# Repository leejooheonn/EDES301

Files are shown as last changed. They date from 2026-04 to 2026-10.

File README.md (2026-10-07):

# Hydra-Gotchi | Embedded Smart Scale






**Hydra-Gotchi** is an ARM-based Linux embedded smart scale built on the BeagleBone Black. The system integrates analog force sensing, custom signal calibration software, and interactive user feedback via an I2C OLED display, GPIO digital inputs, and a piezo audio signal.

---

## 📖 Full Build Log & Hardware Schematics

For detailed hardware schematics, wiring diagrams, laser-cut enclosure vectors, and physical build photographs, check out the full project writeup on **Hackster.io**:

👉 **[View the Hydra-Gotchi Project on Hackster.io](https://www.hackster.io/jl587/hydrationhelper-0f8108) 

---

## 🛠️ Hardware & System Architecture

The hardware architecture combines a custom circuit assembly with a laser-cut, stress-tested enclosure designed to standardize physical load distribution across the Force Sensitive Resistor (FSR) to eliminate mechanical measurement noise.

### Hardware Components
* **SBC (Single-Board Computer):** BeagleBone Black (AM335x ARM Cortex-A8)
* **Weight Sensing:** Force Sensitive Resistor (FSR) connected via Analog-to-Digital Converter (ADC)
* **Visual Display:** SSD1306 OLED Display interfaced via **I2C**
* **Inputs & Audio:** Digital push button (**GPIO**) and Piezoelectric Buzzer (**GPIO**)
* **Physical Assembly:** Custom soldered PCB assembly housed in a laser-cut acrylic enclosure

### Block Diagram

```text
  +--------------------------------------------------------------+
  |                      BeagleBone Black                        |
  |                                                              |
  |   +-------------+      +-------------+      +------------+   |
  |   |   ADC Pin   |      |  I2C Bus    |      | GPIO Pins  |   |
  |   +------+------+      +------+------+      +-----+------+   |
  +----------|--------------------|-------------------|----------+
             |                    |                   |
             v                    v                   v
     [ FSR Sensor ]        [ OLED Display ]     [ Push Button / ]
    (Analog Weight)         (128x64 I2C)        [ Piezo Buzzer  ]

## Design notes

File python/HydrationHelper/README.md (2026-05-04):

<h1>HydrationHelper</h1>

## About the Project 
HydrationHelper is a tool to help people reach their daily water goals. It works to motivate users to drink water by having a virtual pet track the weight of the water bottle and setting a time period for the water bottle to be finished by. The sensor then checks the water bottle at the end of the time period and depending on if the water is full or empty, the virtual pet acts accordingly. 

## Features
* Goal setting: the users can set their time goal for finishing their water bottle
* Calibration: tracks the weight of the full water bottle and the empty water bottle to calibrate the program
* Project presentation: the project proposal can be found in the `docs/` folder

## Repository Structure
* `docs/` - Contains the project presentation and other documentation.
* `HydrationHelper/` - *Contains source code, and images used for the virtual pet*

## Installation and Set-up 
To run this project locally, ensure you have Python3 installed. 
1) Clone the repository
2) Install the required dependencies
   `pip install Adafruit-BBIO`
   `pip install Pillow`
   `pip install Adafruit-Blinka`
   `pip install adafruit-circuitpython-ssd1306`
3) Run the application by entering the HydrationHelper directory and run `python3 calibration.py` to calibrate and then `python3 main.py` to start the HydrationHelper

> **Troubleshooting:** If you receive a "Permission Denied" error regarding hardware access (ADC or I2C), your user may not have the correct permissions. In that case, you can run the program with administrator privileges: `sudo python3 main.py` (Note: If you need to run it with sudo, you may need to install the requirements globally using `sudo pip3 install -r {dependency}`).

## Built With
* Python, BeagleBoard

# Author
* Jooheon Lee EDES301

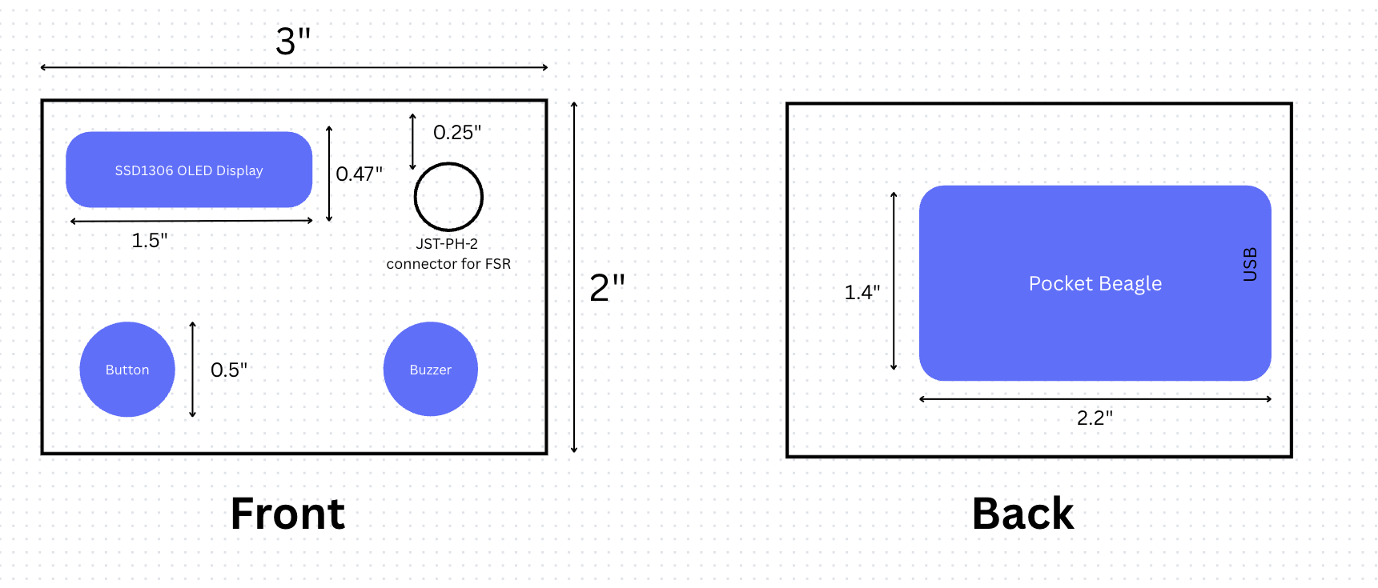
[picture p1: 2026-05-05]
project_02/docs/updated_mechanical_diagram.png

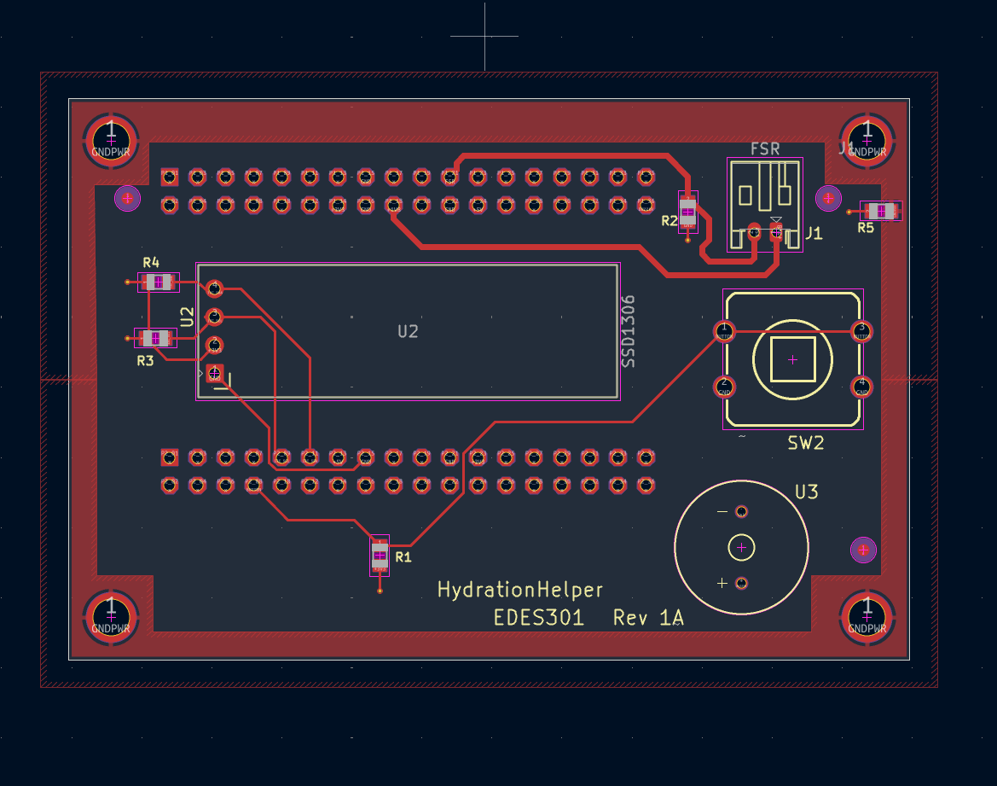
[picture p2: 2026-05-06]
project_02/docs/front_layers.png

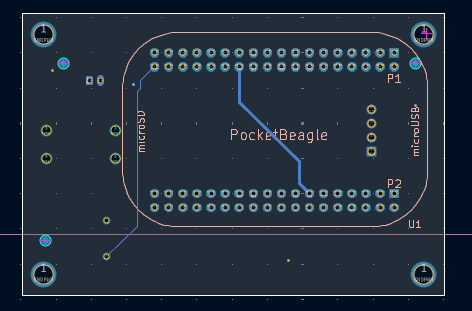
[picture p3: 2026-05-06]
project_02/docs/back_layers.png

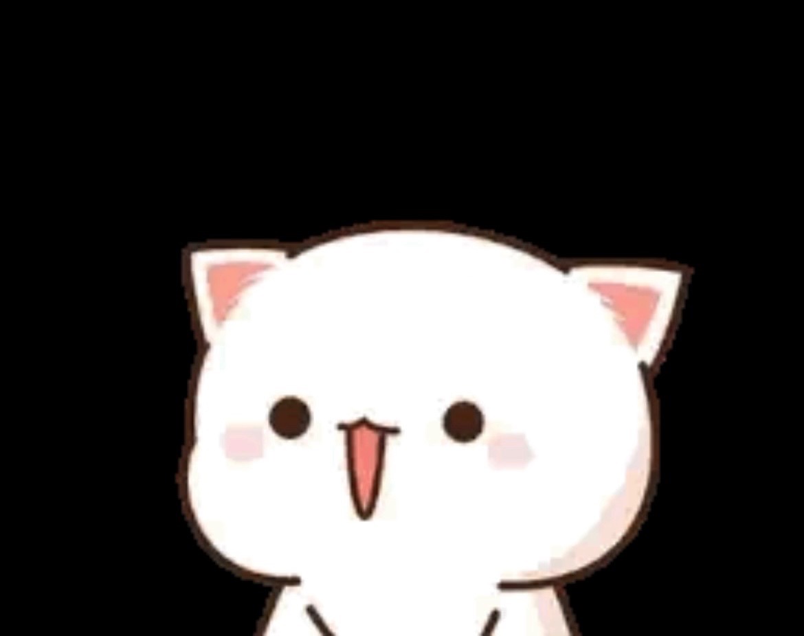
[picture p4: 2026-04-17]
python/HydrationHelper/jumping_cat_3.jpeg

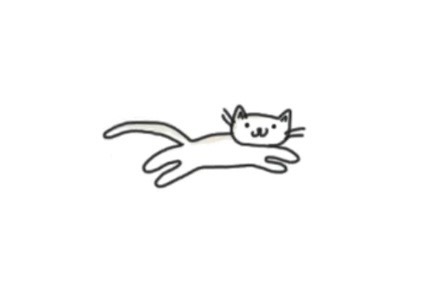
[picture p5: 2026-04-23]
python/HydrationHelper/running_cat_1.jpeg

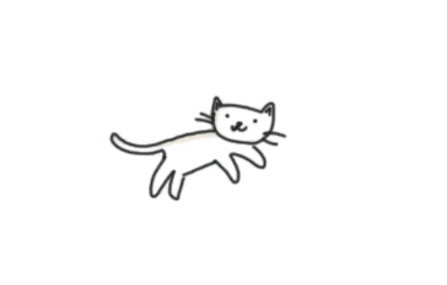
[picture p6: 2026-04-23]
python/HydrationHelper/running_cat_6.jpeg

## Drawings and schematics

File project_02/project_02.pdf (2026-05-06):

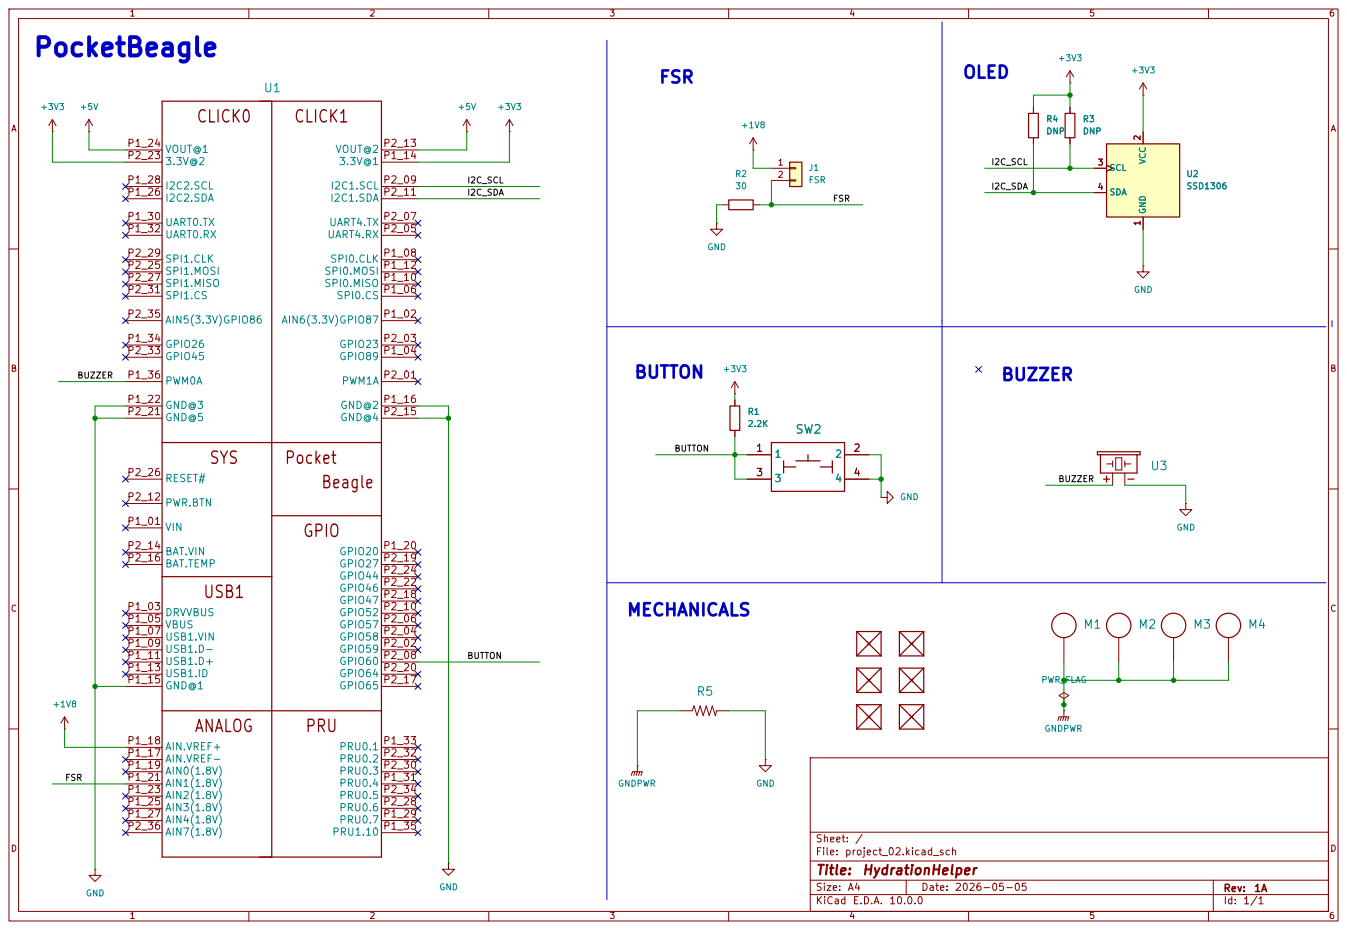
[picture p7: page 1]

Size: A4 | Rev: 1A

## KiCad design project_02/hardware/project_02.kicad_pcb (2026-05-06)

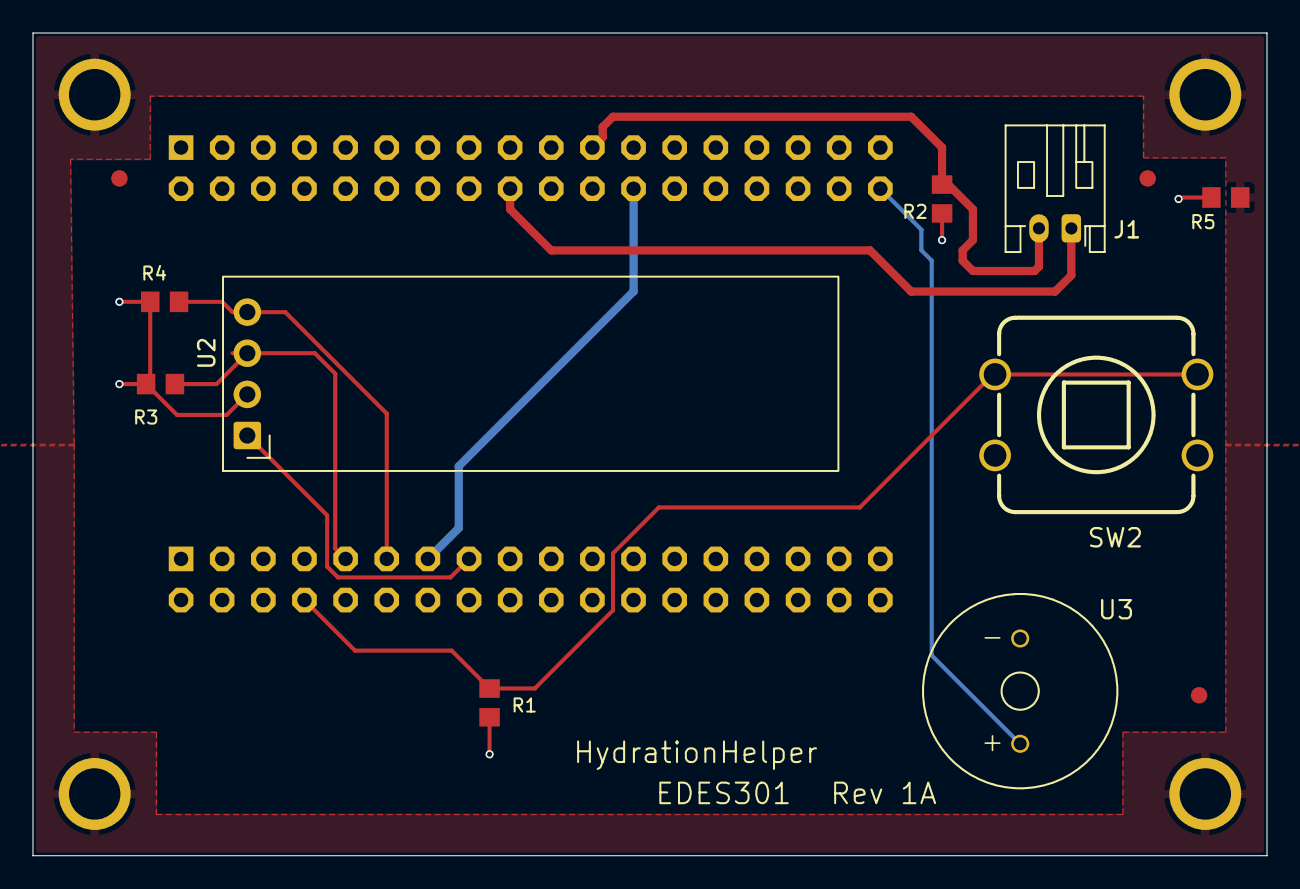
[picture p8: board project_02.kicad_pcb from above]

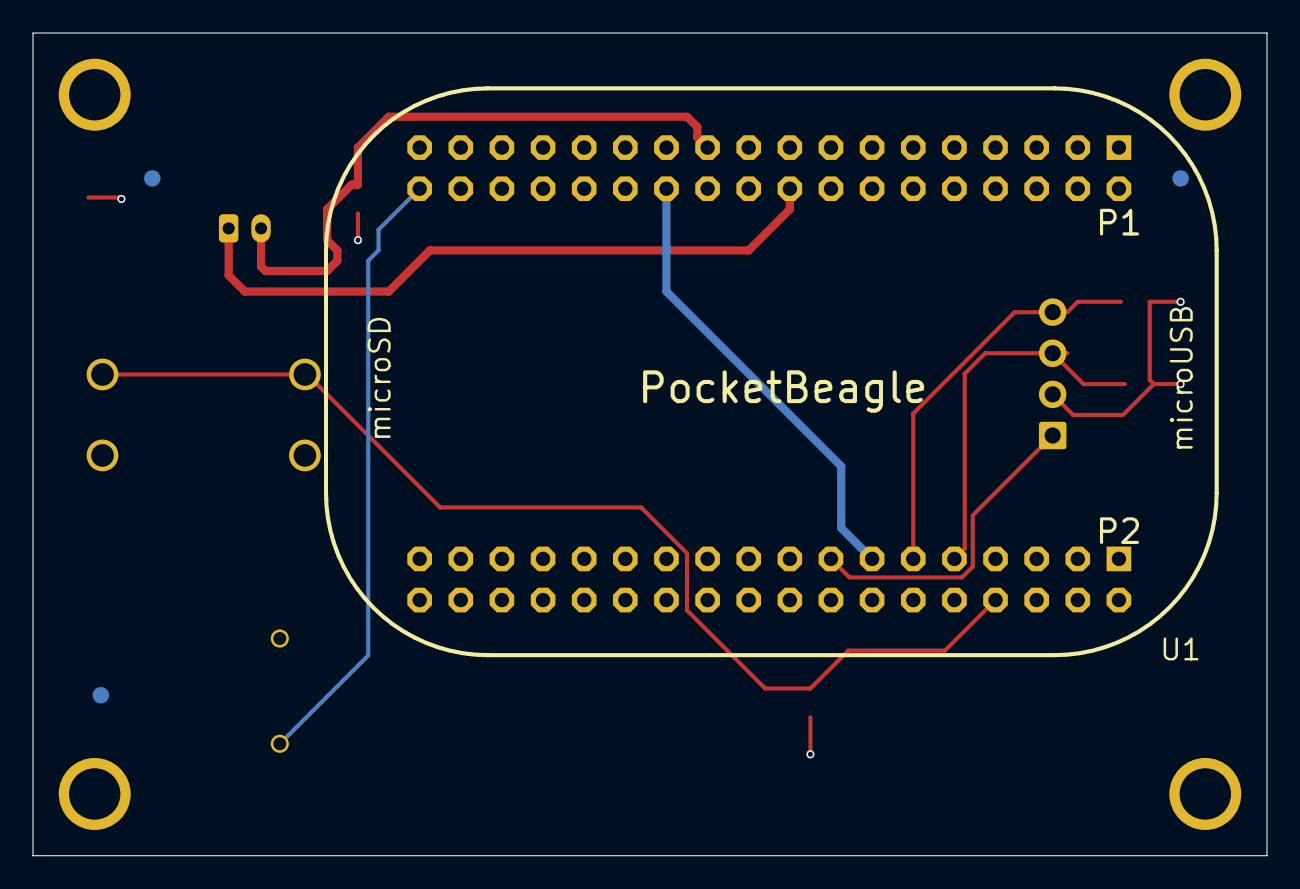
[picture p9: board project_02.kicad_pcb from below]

Board: 4 copper layers, 76.2 x 50.8 mm, 20 parts (4 on the bottom side), 10 nets.

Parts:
FUD1, FUD2, FUD3, FUD4, FUD5, FUD6: FIDUCIAL_40MIL
J1: FSR; JST_PH_S2B-PH-K_1x02_P2.00mm_Horizontal
M1, M2, M3, M4: MOUNTING_HOLE
R1: 2.2K; 2.2KR
R2: 30; 30R
R3, R4: DNP; 2.2KR
R5: R0805
SW2: BUTTON_12.5MM
U1: POCKETBEAGLE
U2: SSD1306; ER_OLEDM0.91_1x-I2C
U3: BUZZER_6.5MM

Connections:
+1V8: J1.1, U1.P1_18 (AIN.VREF+)
+3V3: R1.2, R3.1, R4.1, U1.P1_14 (3.3V@1), U1.P2_23 (3.3V@2), U2.2 (VCC)
+5V: U1.P1_24 (VOUT@1), U1.P2_13 (VOUT@2)
/BUTTON: R1.1, SW2.1, SW2.3, U1.P2_08 (GPIO60)
/BUZZER: U1.P1_36 (PWM0A), U3.+
/FSR: J1.2, R2.2, U1.P1_21 (AIN1(1.8V))
/I2C_SCL: R3.2, U1.P2_09 (I2C1.SCL), U2.3 (SCL)
/I2C_SDA: R4.2, U1.P2_11 (I2C1.SDA), U2.4 (SDA)
GND: R2.1, R5.2, SW2.2, SW2.4, U1.P1_15 (GND@1), U1.P1_16 (GND@2), U1.P1_22 (GND@3), U1.P2_15 (GND@4), U1.P2_21 (GND@5), U2.1 (GND), U3.-
GNDPWR: M1.1 (1_1), M2.1 (1_1), M3.1 (1_1), M4.1 (1_1), R5.1

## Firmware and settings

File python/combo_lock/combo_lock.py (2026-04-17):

"""
--------------------------------------------------------------------------
Combination Lock
--------------------------------------------------------------------------
License:   
Copyright 2026 <NAME>

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
1. Redistributions of source code must retain the above copyright notice, this 
list of conditions and the following disclaimer.

2. Redistributions in binary form must reproduce the above copyright notice, 
this list of conditions and the following disclaimer in the documentation 
and/or other materials provided with the distribution.

3. Neither the name of the copyright holder nor the names of its contributors 
may be used to endorse or promote products derived from this software without 
specific prior written permission.

THIS SOFTWARE IS PROVIDED BY THE COPYRIGHT HOLDERS AND CONTRIBUTORS "AS IS" 
AND ANY EXPRESS OR IMPLIED WARRANTIES, INCLUDING, BUT NOT LIMITED TO, THE 
IMPLIED WARRANTIES OF MERCHANTABILITY AND FITNESS FOR A PARTICULAR PURPOSE ARE 
DISCLAIMED. IN NO EVENT SHALL THE COPYRIGHT HOLDER OR CONTRIBUTORS BE LIABLE 
FOR ANY DIRECT, INDIRECT, INCIDENTAL, SPECIAL, EXEMPLARY, OR CONSEQUENTIAL 
DAMAGES (INCLUDING, BUT NOT LIMITED TO, PROCUREMENT OF SUBSTITUTE GOODS OR 
SERVICES; LOSS OF USE, DATA, OR PROFITS; OR BUSINESS INTERRUPTION) HOWEVER 
CAUSED AND ON ANY THEORY OF LIABILITY, WHETHER IN CONTRACT, STRICT LIABILITY, 
OR TORT (INCLUDING NEGLIGENCE OR OTHERWISE) ARISING IN ANY WAY OUT OF THE USE 
OF THIS SOFTWARE, EVEN IF ADVISED OF THE POSSIBILITY OF SUCH DAMAGE.
--------------------------------------------------------------------------

Use the following hardware components to make a programmable combination lock:  
  - HT16K33 Display
  - Button
  - Red LED
  - Green LED
  - Potentiometer (analog input)
  - Servo

Requirements:
  - Hardware:
    - When locked:   Red LED is on; Green LED is off; Servo is "closed"; Display is unchanged
    - When unlocked: Red LED is off; Green LED is on; Servo is "open"; Display is "----"
    - Display shows value of potentiometer (raw value of analog input divided by 8)
    - Button
      - Waiting for a button press should allow the display to update (if necessary) and return any values
      - Time the button was pressed should be recorded and returned
    - User interaction:
      - Needs to be able to program the combination for the “lock”
        - Need to be able to input three values for the combination to program or unlock the “lock”
      - Combination lock should lock when done programming and wait for combination input
      - If combination is unsuccessful, the lock should go back to waiting for combination input
      - If combination was successful, the lock should unlock
        - When unlocked, pressing button for less than 2s will re-lock the lock; greater than 2s will allow lock to be re-programmed

Uses:
  - HT16K33 display library developed in class
    - Library updated to add "set_digit_raw()", "set_colon()"

"""
import time
import sys
import os
 
sys.path.append('/var/lib/cloud9/EDES301/python')

import ht16k33           as HT16K33
import button             as BUTTON
import potentiometer as POT
import servo               as SERVO
import led                   as LED
from buzzer import buzzer_music         as MUSIC

# ------------------------------------------------------------------------
# Constants
# ------------------------------------------------------------------------

SERVO_LOCK         = 100     # Fully anti-clockwise
SERVO_UNLOCK       = 0       # Fully clockwise

POT_DIVIDER        = 8       # Divider used to help reduce potentiometer granularity

# ------------------------------------------------------------------------
# Global variables
# ------------------------------------------------------------------------

# None

# ------------------------------------------------------------------------
# Functions / Classes
# ------------------------------------------------------------------------

class CombinationLock():
    """ CombinationLock """
    reset_time     = None
    button         = None
    red_led        = None
    green_led      = None
    potentiometer  = None
    servo          = None
    display        = None
    buzzer         = None
    debug          = None
    
    def __init__(self, reset_time=2.0, button="P2_35", 
                       red_led="P2_6", green_led="P2_4",
                       potentiometer="P1_19", servo="P1_36", 
                       i2c_bus=1, i2c_address=0x70,
                       buzzer="P2_1", debug=False):
        """ Initialize variables and set up display """

        self.reset_time     = reset_time
        self.button         = BUTTON.Button(button)
        self.red_led        = LED.LED(red_led)
        self.green_led      = LED.LED(green_led)
        self.potentiometer  = POT.Potentiometer(potentiometer)
        self.servo          = SERVO.Servo(servo, default_position=SERVO_UNLOCK)
        self.display        = HT16K33.HT16K33(i2c_bus, i2c_address)
        self.debug          = debug
        self.buzzer         = MUSIC.BuzzerMusic(buzzer)
        self._setup()
    
    # End def
    
    
    def _setup(self):
        """Setup the hardware components."""

        # Button / LEDs / Potentiometer / Servo 
        #   - All initialized by libraries when instanitated
        
        # set default state 
        self.unlock()

    # End def


    def lock(self):
        """Lock the lock:
               - Turn on red LED; Turn off green LED
               - Set servo to closed
        """
        if self.debug:
            print("lock()")
        
        # Set LEDs
        self.green_led.off()
        self.red_led.on()
        # Set servo to "locked"
        self.servo.turn(SERVO_LOCK)

    # End def


    def unlock(self):
        """Unlock the lock.
               - Turn off red LED; Turn on green LED
               - Set servo to open
               - Set display to "----"
        """
        if self.debug:
            print("unlock()")
            
        # Set LEDs
        self.green_led.on()
        self.red_led.off()
        
        # Set servo to "unlocked"
        self.servo.turn(SERVO_UNLOCK)

        # Set display to dash
        self.set_display_dash()
        
        self.buzzer.play_song_from_list(1)

    # End def


    def show_analog_value(self):
        """Show the analog value on the screen:
               - Read raw analog value
               - Divide by 4 (remove two LSBs)
               - Display value
               - Return value
        """
        if self.debug:
            print("show_analog_value()")
            
        # Read value from Potentiometer
        value = self.potentiometer.get_value()
        
        # Divide value by POT_DIVIDER
        value = int(value // POT_DIVIDER)
        
        # Update display (must be an integer)
        self.display.update(value)
        
        # Return value
        return value

    # End def


    def input_combination(self):
        """Input a combination for the lock:
               - Wait for a button press doing nothing (start of user inputing combination)
               - Repeat 3 time:
                 - Wait for button press; show analog value
                 - Record analog value
               - Return combination
        """
        # Initialize combination array
        combination = [None, None, None]
        
        for i in range(3):
            # Update display with current input
            self.set_display_input(i+1)

            # Wait for button press (do nothing)
            self.button.wait_for_press()
            
            # Set button unpressed callback function
            self.button.set_unpressed_callback(self.show_analog_value)

            # Wait for button press (show analog value)
            self.button.wait_for_press()

            # Get callback function value from button
            value = self.button.get_unpressed_callback_value()
            
            # Remove button unpressed callback 
            self.button.set_unpressed_callback(None)

            # Record Analog value
            combination[i] = value

        if self.debug:
            print(combination)
            
        return combination

    # End def


    def run(self):
        """Execute the main program."""
        combination                  = [None, None, None]  # Combination
        combo_attempt                = [None, None, None]  # Combination attempt
        program                      = True
        
        # Lock was unlocked in _setup()
        time.sleep(1)
                
        while(1):
            
            # Program the lock
            if (program):
                if self.debug:
                    print("Program Lock")
                
                # Set display
                self.set_display_prog()
                
                # Wait for button press (do nothing)
                self.button.wait_for_press()
                
                # Get combination
                combination = self.input_combination()
                
                # Lock the lock
                self.lock()
                
                # Set program lock to False
                program = False

            # Set Display to try combination
            self.set_display_try()

            # Wait for button press (do nothing)
            self.button.wait_for_press()
            
            # Get combination
            combo_attempt = self.input_combination()

            # Compare attempt against combination
            combo_pass = True

            for i in range(2):
                if combination[i] != combo_attempt[i]:
                    combo_pass = False

            # If combination passed
            if combo_pass:
                if self.debug:
                    
                    print("Combination Passed")
                # Unlock the lock
                self.unlock()
                
                # Wait for button press
                self.button.wait_for_press()
                
                # Get press duration
                duration = self.button.get_last_press_duration()
                
                # If greater than reset_time, program lock, else lock the lock
                if duration > self.reset_time:
                    program = True
                else:
                    self.lock()
            time.sleep(1)

    # End def


    def set_display_prog(self):
        """Set display to word "Prog" """
        self.display.text("Prog")

    # End def


    def set_display_try(self):
        """Set display to word " go " """
        self.display.text(" go ")

    # End def


    def set_display_input(self, number):
        """Set display to word "in: #" """
        self.display.text("in {0}".format(number))

    # End def


    def set_display_dash(self):
        """Set display to word "----" """
        self.display.text("----")

    # End def


    def cleanup(self):
        """Cleanup the hardware components."""
        
        # Set Display to show program is complete
        self.display.text("done")

        # Clean up hardware
        self.button.cleanup()
        self.red_led.cleanup()
        self.green_led.cleanup()
        self.potentiometer.cleanup()
        self.servo.cleanup()

    # End def

# End class



# ------------------------------------------------------------------------
# Main script
# ------------------------------------------------------------------------

if __name__ == '__main__':

    print("Program Start")

    # Create instantiation of the lock
    combo_lock = CombinationLock(debug=True)

    try:
        # Run the lock
        combo_lock.run()

    except KeyboardInterrupt:
        # Clean up hardware when exiting
        combo_lock.cleanup()

    print("Program Complete")

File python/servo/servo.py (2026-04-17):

"""
--------------------------------------------------------------------------
Servo Driver
--------------------------------------------------------------------------
License:   
Copyright 2021-2026 - Jooheon

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
1. Redistributions of source code must retain the above copyright notice, this 
list of conditions and the following disclaimer.

2. Redistributions in binary form must reproduce the above copyright notice, 
this list of conditions and the following disclaimer in the documentation 
and/or other materials provided with the distribution.

3. Neither the name of the copyright holder nor the names of its contributors 
may be used to endorse or promote products derived from this software without 
specific prior written permission.

THIS SOFTWARE IS PROVIDED BY THE COPYRIGHT HOLDERS AND CONTRIBUTORS "AS IS" 
AND ANY EXPRESS OR IMPLIED WARRANTIES, INCLUDING, BUT NOT LIMITED TO, THE 
IMPLIED WARRANTIES OF MERCHANTABILITY AND FITNESS FOR A PARTICULAR PURPOSE ARE 
DISCLAIMED. IN NO EVENT SHALL THE COPYRIGHT HOLDER OR CONTRIBUTORS BE LIABLE 
FOR ANY DIRECT, INDIRECT, INCIDENTAL, SPECIAL, EXEMPLARY, OR CONSEQUENTIAL 
DAMAGES (INCLUDING, BUT NOT LIMITED TO, PROCUREMENT OF SUBSTITUTE GOODS OR 
SERVICES; LOSS OF USE, DATA, OR PROFITS; OR BUSINESS INTERRUPTION) HOWEVER 
CAUSED AND ON ANY THEORY OF LIABILITY, WHETHER IN CONTRACT, STRICT LIABILITY, 
OR TORT (INCLUDING NEGLIGENCE OR OTHERWISE) ARISING IN ANY WAY OUT OF THE USE 
OF THIS SOFTWARE, EVEN IF ADVISED OF THE POSSIBILITY OF SUCH DAMAGE.
--------------------------------------------------------------------------

SG90 Servo Driver

API:
  Servo(pin)
    - Provide pin that the Servo is connected
  
    turn(percentage)
      -   0 = Fully clockwise
      - 100 = Fully anti-clockwise

"""
import Adafruit_BBIO.PWM as PWM

# ------------------------------------------------------------------------
# Constants
# ------------------------------------------------------------------------

SG90_FREQ               = 50                  # 20ms period (50Hz)
SG90_POL                = 0                   # Rising Edge polarity
SG90_MIN_DUTY           = 5                   # 1ms pulse (5% duty cycle)  -- Fully clockwise (right)
SG90_MAX_DUTY           = 10                  # 2ms pulse (10% duty cycle) -- Fully anti-clockwise (left)

# ------------------------------------------------------------------------
# Global variables
# ------------------------------------------------------------------------

# None

# ------------------------------------------------------------------------
# Functions / Classes
# ------------------------------------------------------------------------

class Servo():
    """ CombinationLock """
    pin       = None
    position  = None
    
    def __init__(self, pin=None, default_position=0):
        """ Initialize variables and set up the Servo """
        if (pin == None):
            raise ValueError("Pin not provided for Servo()")
        else:
            self.pin = pin

        self.position = default_position
        
        self._setup(default_position)
    
    # End def
    
    
    def _setup(self, default_position):
        """Setup the hardware components."""
        # Initialize Servo; Servo should be in "default position"
        
        PWM.start(self.pin, self._duty_cycle_from_position(default_position), SG90_FREQ, SG90_POL)
        
    # End def

    
    def _duty_cycle_from_position(self, position):
        """ Return the duty cycle to set the provided position """
        return ((SG90_MAX_DUTY - SG90_MIN_DUTY) * (position / 100)) + SG90_MIN_DUTY    
        
    # End def
    
    
    def get_position(self):
        """ Return the position of the servo """
        return self.position
    
    # End def
    

    def turn(self, position):
        """ Turn Servo to the desired position based on percentage of motion range
        
              0% = Fully clockwise (right)
            100% = Fully anti-clockwise (left)      
        """
        # Record the current position
        self.position = position
        
        # Set PWM duty cycle based on position
        duty_cycle = self._duty_cycle_from_position(position)
        
        PWM.set_duty_cycle(self.pin, duty_cycle)
        print("Turning servo to position {0} using duty cycle {1}".format(position, duty_cycle))

    # End def


    def cleanup(self):
        """Cleanup the hardware components."""
        # Stop servo
        PWM.stop(self.pin)
        PWM.cleanup()
        
    # End def

# End class



# ------------------------------------------------------------------------
# Main script
# ------------------------------------------------------------------------

if __name__ == '__main__':
    import time
    
    print("Servo Test")

    # Create instantiation of the servo
    servo = Servo("P1_36")

    # Use a Keyboard Interrupt (i.e. "Ctrl-C") to exit the test
    print("Use Ctrl-C to Exit")
    
    try:
        while(1):
            # Turn Servo anti-clockwise
            servo.turn(0)
            print("Current position = {0}%".format(servo.get_position()))
            time.sleep(1)
        
            servo.turn(100)
            print("Current position = {0}%".format(servo.get_position()))
            time.sleep(1)
        
    except KeyboardInterrupt:
        pass

    # Clean up hardware when exiting
    servo.cleanup()

    print("Test Complete")

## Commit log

2026-02-24 Added button functionality for HW 4
2026-04-17 Add button, buzzer, and other project files
    [buzzer.py, calibration.py, combo_lock.py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]
